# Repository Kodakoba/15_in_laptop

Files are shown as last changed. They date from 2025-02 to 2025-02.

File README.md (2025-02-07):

# anyon_e 15

A higher end, more gaming focused, open source laptop fork inspired by the anyon_e 13. 

Please check out the original repo, and tip the original creator! I'm just modifying this out of inspiration.

_aka project 'Arctic Wolf'_
#
#### Features (including added ones):

- RK3588 SoC Motherboard
  - CM3588-based
  - USB-C USB3.1 Gen 1
  - Supports up to 32GB LPDDR5 or 16gb LPDDR4X
  - **I really reccomend a version with eMMC flash for the boot image**
- Powertrain
  - ESP32-S3 embedded controller
  - ~60Wh Li-ion battery pack (maybe x2 if money/space allows)
- Peripherals
  - Glass-topped multi-touch trackpad
  - HD AMOLED 15.6" display
  - Anodized aluminum CNC chassis (i hope, most likely will end up being 304 grade aluminum)
- Additions to original project:
  - EasyEDA files for all schematics and PCBs so they're directly orderable. Additionally gonna include another repo for the Autodesk Inventor files, and blobs if needed.
  - modified boards to be cheaper to order - at least the test adapter so far (4layer -> 2layer pcb)
  - RJ45 jack for the on SOM 2.5g ethernet, an MXM slot for a GPU, USB2.0 hub with outside port and connections for wired keyboard(s).
  - revised boards for more features
  - beefier modular cooler for the SOM and MXM module (tba, haven't began anything aside from sketches)
#

Total end cost will be added here, including options and configurations i've bought;
So far the running total is:
 ## 772.37

For:
- Display adapter PCB x 5 (min order, JLCPCB, assembled (i don't have a reflow station)) .......... 116.34
- Azoteq PXM0057-501-S (from Mouser) ............................................................... 66.29
- CM3588 Plus (32GB LPDDR5, + 64gb eMMC) module, NAS board (for testing) and 12v 4A power supply .. 259.60
- MISC development boards and converters on amazon (MXM, E key adapter, SSD) ...................... 164.28*
- Sonnet GPU-RX55-TB3-S eGPU puck for the MXM 5500XT inside ....................................... 165.86

Theorized total (for a complete laptop, sans development boards):
 ## 1580.73 (USD, excluding chassis)
For:
- CM3588 Plus (32GB LPDDR5, + 64gb eMMC) module, NAS board (for testing) and 12v 4A power supply .. 210.00 (it's expected you get this entirely for loading the eMMC boot stuff)
- (MB) Custom 6 layer PCB (130mm x 215mm rough estimate), options detailed at final ordering ...... 155.23 (not including assembly!!!)
- Radeon 5500XT MXM 3.0 Module .................................................................... 165.86 (taken from a "broken" eGPU puck since the main distributor for MXM gpus appears to be away)
- Battery (x4, with lead time) .................................................................... 146.81
- Battery charging management PCB .................................................................  43.75 (not including assembly!!!)
- Samsung ATNA56YX03-0 Panel, adhesive strips, and connecting ribbon .............................. 241.47
- Mousepad old stock + generic backlit ribbon keyboard (Dell or Lenovo) ........................... 104.29
- Misc Connectors, a sum of all BoMs .............................................................. 327.89 (from a few sites,aggregated. this price will go up over time!!!)
- Webcamera, pair of shottky diodes, and a cable ..................................................  16.29 (ebay!)
- Chassis, CNC milled, with ABS or resin bezels ................................................... unknown at this time

#

Hypothetically to cut costs you could choose a base model CM3588 (8gb with 64gb eMMC), choose a cheaper monitor, skip the MXM card, and get the costs down to under 900$ US but i'm making this with no expenses spared as much as possible.

#

I've started to include .epro "nightly" revisions for this project as well, in case you wanna see progress over time.

#

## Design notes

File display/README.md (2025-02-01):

# Display

Using the ATNA56YX03-0 15.6" HD AMOLED display from Samsung.

https://www.panelook.com/ATNA56YX03-0_Samsung_15.6_OLED_overview_49379.html

The datasheet is very expensive to acquire.
I'm assuming 30 pin EDP -> 40pin shouldn't be too bad

eDP 40 pin connector: IPEX 20455-040E
eDP 40 to 30 pin cable: https://www.amazon.com/gp/product/B077V8KKXS/

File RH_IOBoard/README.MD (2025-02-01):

# THE IO BOARD
to be mounted below or above the BMS BOARD

IO:
USB TYPE A
(maybe) SD CARD

should be a simple 2 layer PCB with ribbons :)

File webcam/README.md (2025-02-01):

# Webcam

I really want this to be a solid daily driver for potentially years to come, so a functional webcam is a must
luckily, there's room!!!

https://www.ebay.com/itm/292754652137

Generic: CNO314-0VO3
Used in Acer Extensa laptop

additionally, there's ways to make this USB too! Which is an easy way to add everything as a generic HID usb device

https://www.instructables.com/Salvaging-and-Reusing-an-Old-Laptop-Camera-to-USB-/

the IO board (in development) will help with this!

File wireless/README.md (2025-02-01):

# Wireless

Looking at Intel's AX210 or RTL8852BE, assuming M.2 E Key connection is functional.

https://us.rs-online.com/product/okdo/ra007-a8/74063355/

Edit: I'm gonna use a very similar one, the RTL8822CE chipset as its supported by the CM3588 officially.

https://www.amazon.com/gp/product/B0C6Q9PJKT/

Not a crazy performance model by any means, but the drivers should be better supported. (fingers crossed...)

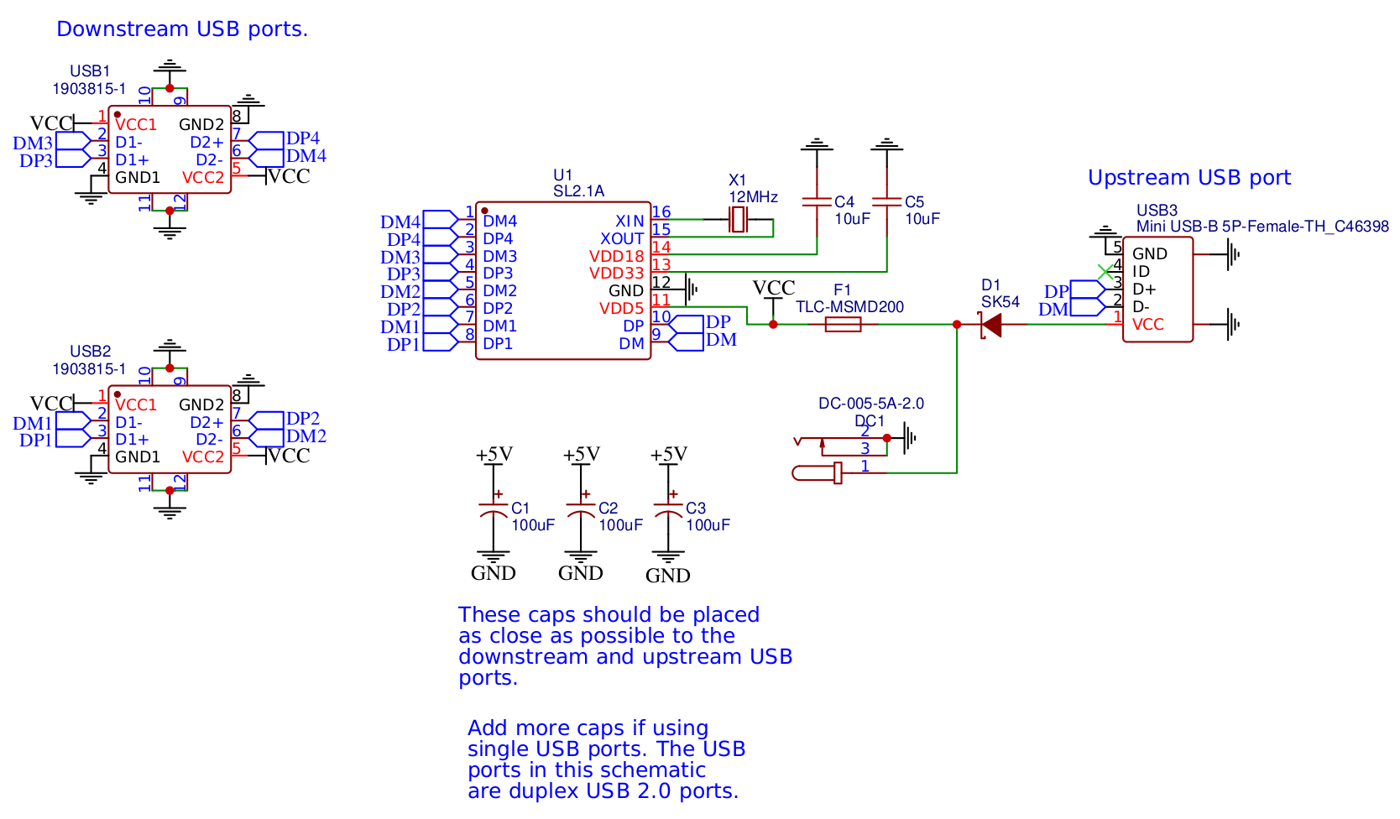
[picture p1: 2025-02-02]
pdfs/USB2.0HUB4PORT.png

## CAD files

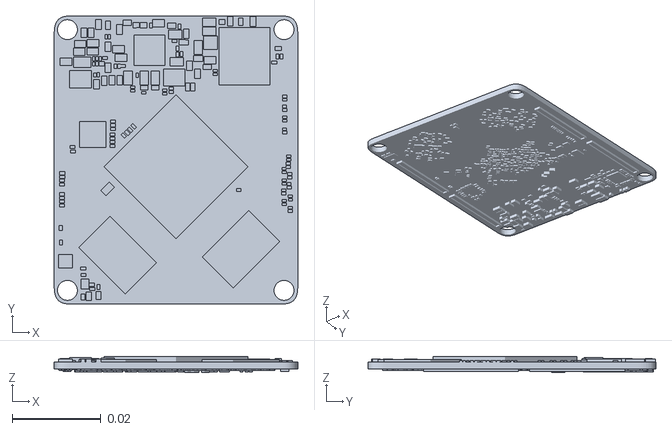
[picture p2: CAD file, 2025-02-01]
motherboard_OG_rev1.0/CM3588 3D/CM3588.stl
0.055 x 0.065 x 0.00366

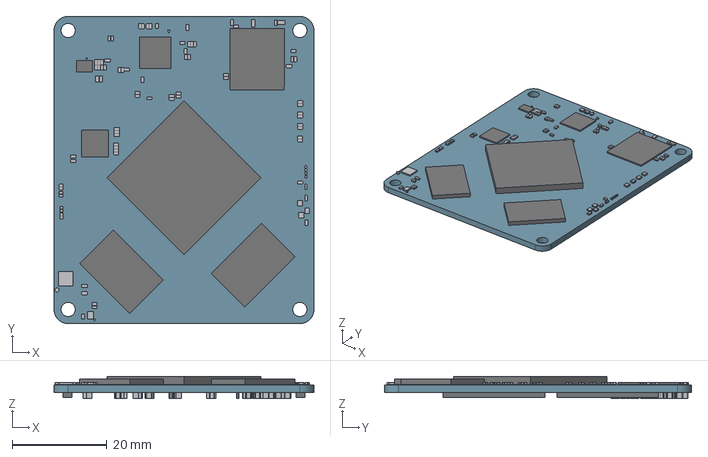
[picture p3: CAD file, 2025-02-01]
motherboard_OG_rev1.0/CM3588 3D/CM3588_3D.step
55.0 x 65.0 x 4.70 mm

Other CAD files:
motherboard_OG_rev1.0/CM3588 3D/CM3588.obj

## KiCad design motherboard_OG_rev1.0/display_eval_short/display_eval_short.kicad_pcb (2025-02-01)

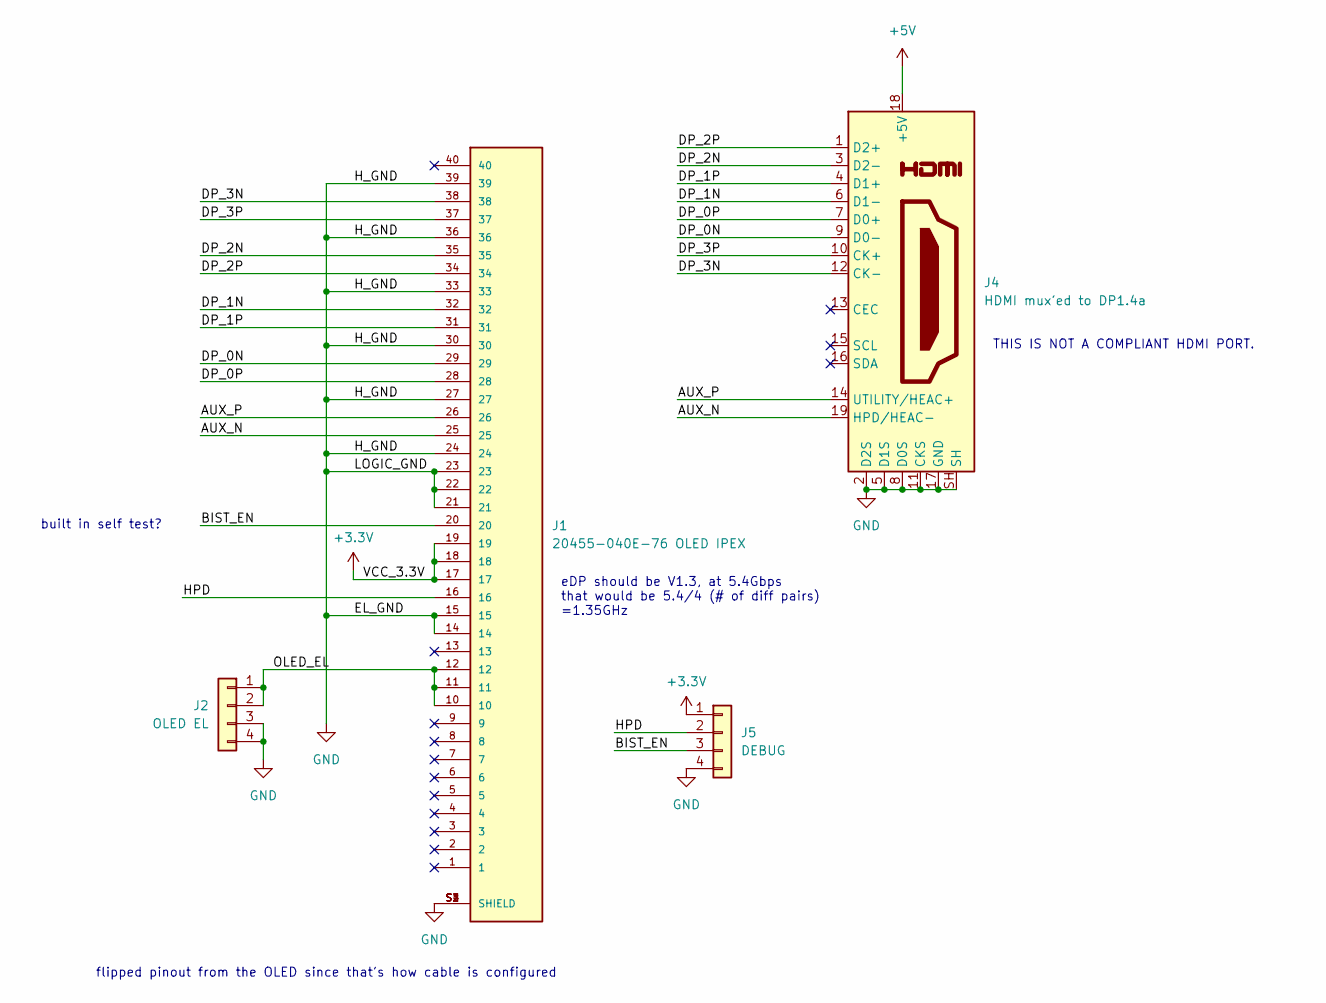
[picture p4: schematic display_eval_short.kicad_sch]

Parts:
J1: 20455-040E-76 OLED IPEX; IPEX_20455-040E-76; LCSC C7527731
J2: OLED EL; PinHeader_1x04_P2.54mm_Vertical
J4: HDMI mux'ed to DP1.4a; HDMI-SMD_HYC109-HDMIA19-160; LCSC C720616
J5: DEBUG; PinHeader_1x04_P2.54mm_Vertical

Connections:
+3.3V: J1.17, J1.18, J1.19, J5.1
+5V: J4.18 (+5V)
/AUX_N: J1.25, J4.19 (HPD/HEAC-)
/AUX_P: J1.26, J4.14 (UTILITY/HEAC+)
/BIST_EN: J1.20, J5.3
/DP_0N: J1.29, J4.9 (D0-)
/DP_0P: J1.28, J4.7 (D0+)
/DP_1N: J1.32, J4.6 (D1-)
/DP_1P: J1.31, J4.4 (D1+)
/DP_2N: J1.35, J4.3 (D2-)
/DP_2P: J1.34, J4.1 (D2+)
/DP_3N: J1.38, J4.12 (CK-)
/DP_3P: J1.37, J4.10 (CK+)
/HPD: J1.16, J5.2
/OLED_EL: J1.10, J1.11, J1.12, J2.1, J2.2
GND: J1.14, J1.15, J1.21, J1.22, J1.23, J1.24, J1.27, J1.30, J1.33, J1.36, J1.39, J1.S1 (SHIELD), J1.S2 (SHIELD), J1.S3 (SHIELD), J1.S4 (SHIELD), J2.3, J2.4, J4.2 (D2S), J4.5 (D1S), J4.8 (D0S), J4.11 (CKS), J4.17 (GND), J4.SH, J5.4

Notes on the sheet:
THIS IS NOT A COMPLIANT HDMI PORT.
eDP should be V1.3, at 5.4Gbps that would be 5.4/4 (# of diff pairs) =1.35GHz
flipped pinout from the OLED since that's how cable is configured
built in self test?

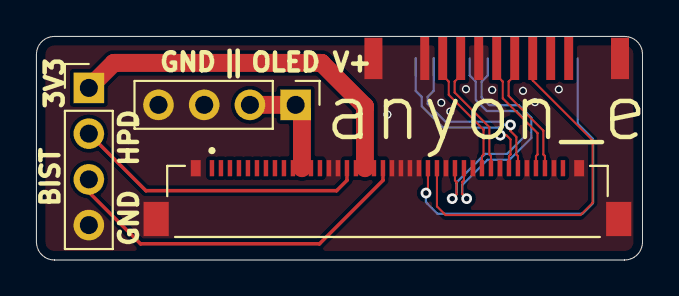
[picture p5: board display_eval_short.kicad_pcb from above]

Board: 4 copper layers, 33.7 x 12.4 mm, 4 parts (1 on the bottom side), 15 nets.

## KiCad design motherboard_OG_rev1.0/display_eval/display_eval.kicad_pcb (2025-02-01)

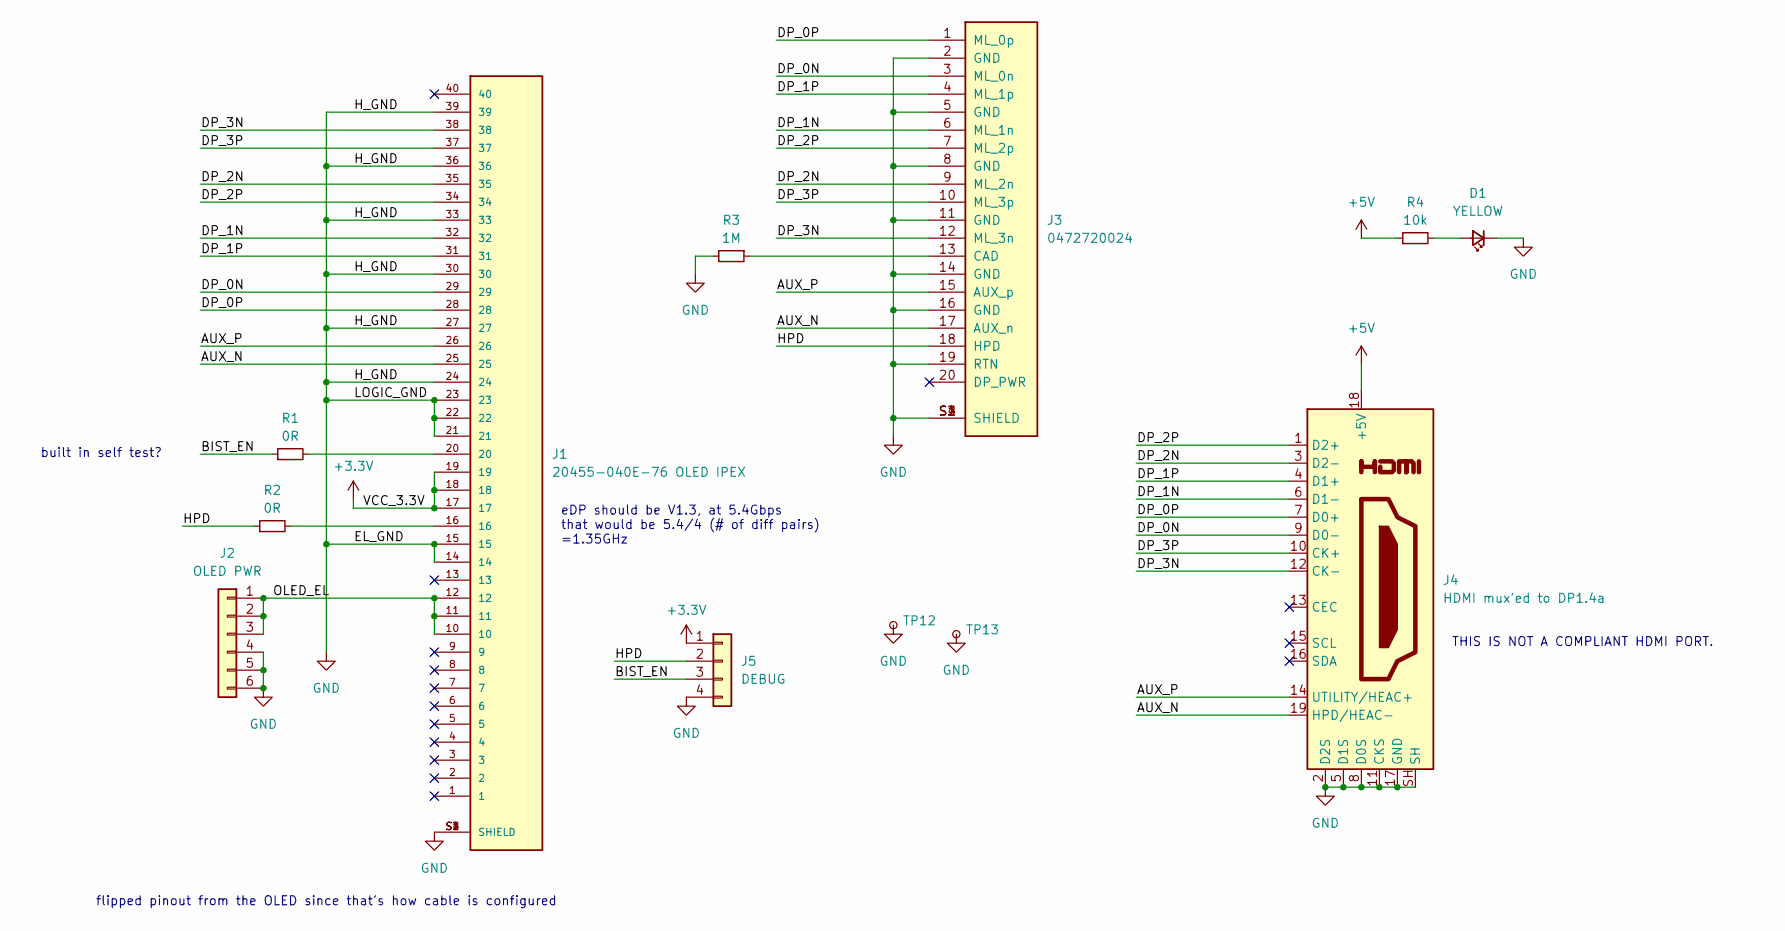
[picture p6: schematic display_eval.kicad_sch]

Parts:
D1: YELLOW; LED_0603_1608Metric; LCSC C2296
J1: 20455-040E-76 OLED IPEX; IPEX_20455-040E-76; LCSC C7527731
J2: OLED PWR; PinHeader_1x06_P2.54mm_Vertical
J3: 0472720024; MOLEX_0472720024; PARTREV D; LCSC C711350
J4: HDMI mux'ed to DP1.4a; HDMI_A_Molex_208658-1001_Horizontal; LCSC C720616
J5: DEBUG; PinHeader_1x04_P2.54mm_Vertical
R1: 0R; R_0603_1608Metric
R2: 0R; R_0603_1608Metric; LCSC C21189
R3: 1M; R_0603_1608Metric; LCSC C22935
R4: 10k; R_0603_1608Metric; LCSC C25804
TP12, TP13: TestPoint_THTPad_D2.0mm_Drill1.0mm

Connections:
+3.3V: J1.17, J1.18, J1.19, J5.1
+5V: J4.18 (+5V), R4.1
/AUX_N: J1.25, J3.17 (AUX_n), J4.19 (HPD/HEAC-)
/AUX_P: J1.26, J3.15 (AUX_p), J4.14 (UTILITY/HEAC+)
/BIST_EN: J5.3, R1.1
/DP_0N: J1.29, J3.3 (ML_0n), J4.9 (D0-)
/DP_0P: J1.28, J3.1 (ML_0p), J4.7 (D0+)
/DP_1N: J1.32, J3.6 (ML_1n), J4.6 (D1-)
/DP_1P: J1.31, J3.4 (ML_1p), J4.4 (D1+)
/DP_2N: J1.35, J3.9 (ML_2n), J4.3 (D2-)
/DP_2P: J1.34, J3.7 (ML_2p), J4.1 (D2+)
/DP_3N: J1.38, J3.12 (ML_3n), J4.12 (CK-)
/DP_3P: J1.37, J3.10 (ML_3p), J4.10 (CK+)
/HPD: J3.18 (HPD), J5.2, R2.1
/OLED_EL: J1.10, J1.11, J1.12, J2.1, J2.2, J2.3
GND: D1.1 (K), J1.14, J1.15, J1.21, J1.22, J1.23, J1.24, J1.27, J1.30, J1.33, J1.36, J1.39, J1.S1 (SHIELD), J1.S2 (SHIELD), J1.S3 (SHIELD), J1.S4 (SHIELD), J2.4, J2.5, J2.6, J3.2 (GND), J3.5 (GND), J3.8 (GND), J3.11 (GND), J3.14 (GND), J3.16 (GND), J3.19 (RTN), J3.S1 (SHIELD), J3.S2 (SHIELD), J3.S3 (SHIELD), J3.S4 (SHIELD), J4.2 (D2S), J4.5 (D1S), J4.8 (D0S), J4.11 (CKS), J4.17 (GND), J4.SH, J5.4, R3.2, TP12.1, TP13.1
unnamed: D1.2 (A), R4.2
unnamed: J1.16, R2.2
unnamed: J1.20, R1.2
unnamed: J3.13 (CAD), R3.1

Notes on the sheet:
THIS IS NOT A COMPLIANT HDMI PORT.
eDP should be V1.3, at 5.4Gbps that would be 5.4/4 (# of diff pairs) =1.35GHz
flipped pinout from the OLED since that's how cable is configured
built in self test?

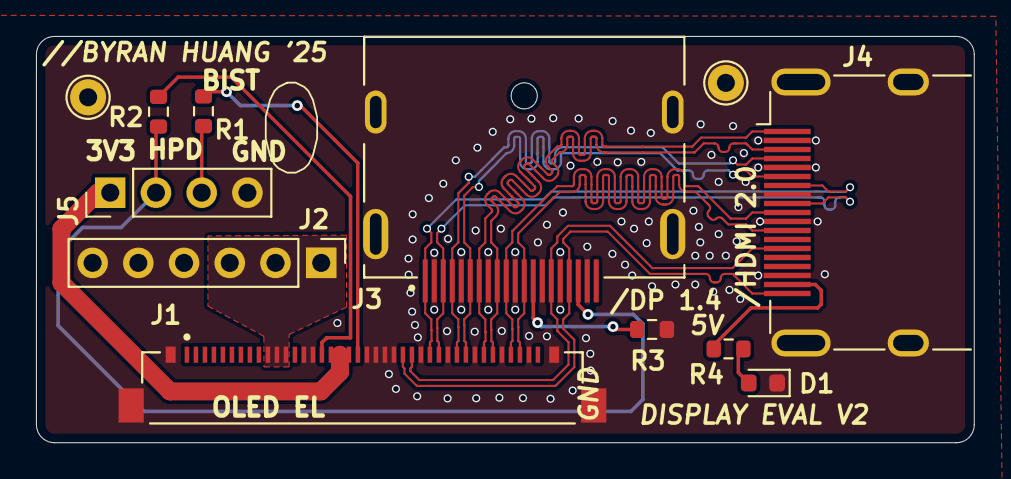
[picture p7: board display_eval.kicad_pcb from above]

Board: 4 copper layers, 52.1 x 22.6 mm, 12 parts (0 on the bottom side), 20 nets.

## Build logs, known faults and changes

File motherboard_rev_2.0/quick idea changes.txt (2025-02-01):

RJ45 jack for the on SOM 2.5g ethernet
MXM 3 slot
USB2.0 hub with outside port
wired keyboard
USB2.0 ribbon riser for webcam
IO board with ribbon connector (for modular? IO on RHS/back)
(mini)HDMI in lines
Move charging port to rear (type C)
Switch out external display connector for DP++ 1.4 (cool omni jack)
make audio switch to speakers and inside mic using audio hotplug detection from 4 pin
(potentially) relocate SD/TF slot to RHS

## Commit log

2025-02-01 Changed File Structure, added temp ideas to come back to, and extended the License.
    [CM3588.obj, CM3588.stl, CM3588_3D.step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]
2025-02-01 added epro files from easyEDA for display adapter board v3 (dual layer)
2025-02-04 Update README to refelect price updates
    pcbs are expensive dawg
2025-02-04 added easyeda file support to repo
    misc cleanup things while i keep drawing schematics in the background
